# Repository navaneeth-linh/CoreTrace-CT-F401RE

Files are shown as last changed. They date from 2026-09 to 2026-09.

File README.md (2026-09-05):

# CT-F401RE Evaluation Board
**Team:** CoreTrace  
**Designer:** S Navaneeth Krishna  
**Institution:** Muthoot Institute of Technology and Science (MITS), Kerala  
**Competition:** Mixed Traces PCB Design Competition — MEC 2026  

---

## Overview
CT-F401RE is a compact STM32F401RET6 evaluation and development board 
designed for the Mixed Traces PCB Design Competition organized by 
Mixed Signals, the Electronics Association of MEC. The board is 
inspired by the STM32 NUCLEO-F401RE reference design and provides 
essential facilities for programming, debugging, and general-purpose 
embedded development.

---

## Features
- STM32F401RET6 LQFP-64 microcontroller
- USB Micro-B interface for power and communication
- SWD debug and programming header (6-pin)
- UART communication header (4-pin)
- SPI communication header (6-pin)
- I2C communication header (4-pin)
- 18 GPIO pins exposed via CN1 and CN2 headers
- 8MHz HSE crystal oscillator
- AMS1117-3.3 LDO voltage regulator (5V → 3.3V)
- 4 LED indicators (PWR / USR / TX / RX)
- Reset tactile button
- User tactile button
- BOOT0 SPDT slide switch
- 100 × 100mm 2-layer PCB
- Designed in KiCad 10.0.5

---

## Design Decisions

### Power Supply
- AMS1117-3.3 LDO chosen for simplicity, availability and low cost
- USB Micro-B as power input via VBUS (5V)
- Bulk capacitors (22µF) on both input and output of regulator
- 100nF ceramic decoupling caps on all MCU VDD pins
- Ferrite bead (120R) on VDDA/VREF+ supply for analog noise filtering
- VCAP1 = 2.2µF for STM32F401RE internal voltage regulator stability

### USB
- 22Ω series resistors on D+ and D− for signal integrity
- Internal 1.5kΩ pullup on D+ for USB Full Speed detection
- USB Micro-B connector on board edge for easy access

### Clock
- 8MHz HSE crystal with 20pF load capacitors
- Crystal placed close to PH0/PH1 pins for short traces

### BOOT0
- SPDT slide switch for easy BOOT0 selection
- FLASH position → normal boot from flash
- BOOT position → bootloader mode
- 10kΩ pulldown resistor as default LOW state

### GPIO
- CN1 exposes: 3.3V, PA0, PA1, PA8, PA9, PA10, PA15, PB1, PB2, GND
- CN2 exposes: 3.3V, PB3, PB4, PB5, PB6, PB7, PB10, PB12, PB13, GND
- All unused PC pins assigned no-connect flags

### PCB
- SMD components throughout for compact layout
- 0402 package for resistors and small capacitors
- 0805 package for LEDs and bulk capacitors
- GND copper pour on both layers
- Track widths: 0.2mm signal, 0.3mm MCU power, 0.5mm 3.3V, 0.8mm VBUS

---

## Design Status

| Task | Status |
|---|---|
| Schematic | ✅ Complete |
| ERC | ✅ Clean (0 errors, 0 warnings) |
| PCB Layout | ✅ Complete |
| Routing | ✅ Complete |
| DRC | ✅ Clean (0 errors, 1 warning) |
| Silkscreen | ✅ Complete |
| BOM | ✅ Complete |
| Documentation | ✅ Complete |

---

## Known Issues and Warnings

### DRC Warning — Footprint Mismatch
**Warning:**    

**Component:** SW1 — BOOT0 SPDT Switch

**Reason:** The SPDT switch footprint was 
modified to fix a silkscreen overlap with 
the board edge cut. The silkscreen of the 
original footprint extended beyond the PCB 
boundary causing a DRC violation. The 
footprint silkscreen was moved inward 
resulting in a minor library mismatch warning.

**Impact:** None — footprint is electrically 
correct and physically accurate. This is a 
cosmetic library mismatch only.

**DRC Summary:**
| Type | Count |
|---|---|
| Errors | 0 ✅ |
| Warnings | 1 ⚠️ |
| Unconnected nets | 0 ✅ |

---

## Screenshots

### Block Diagram 
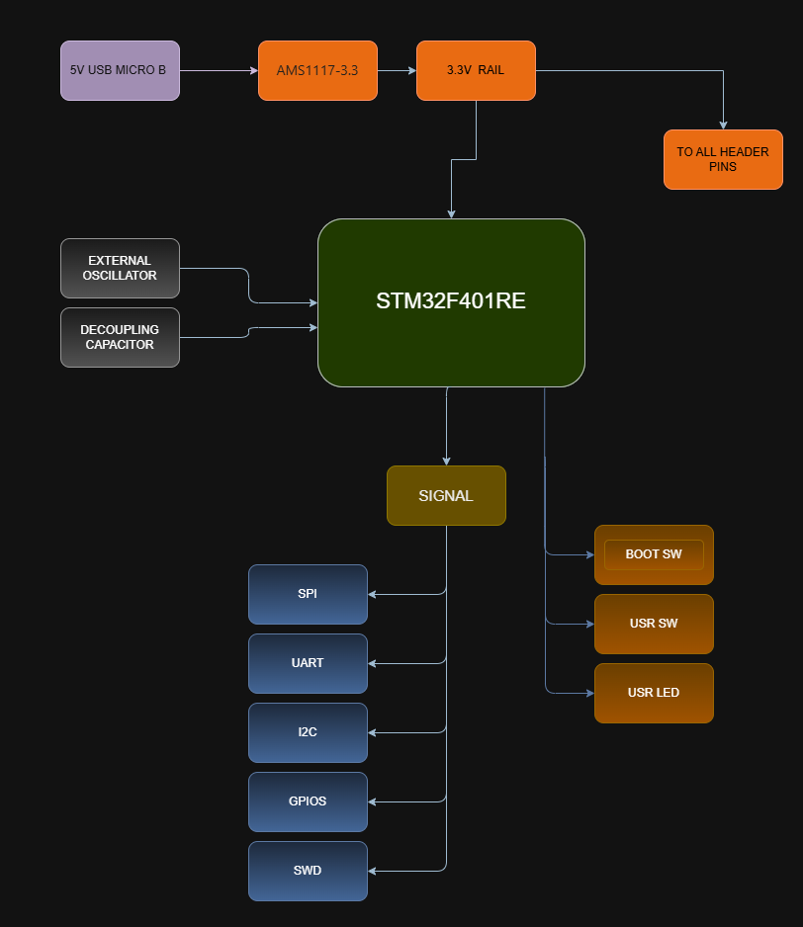
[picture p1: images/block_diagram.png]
Block Diagram


### Schematic
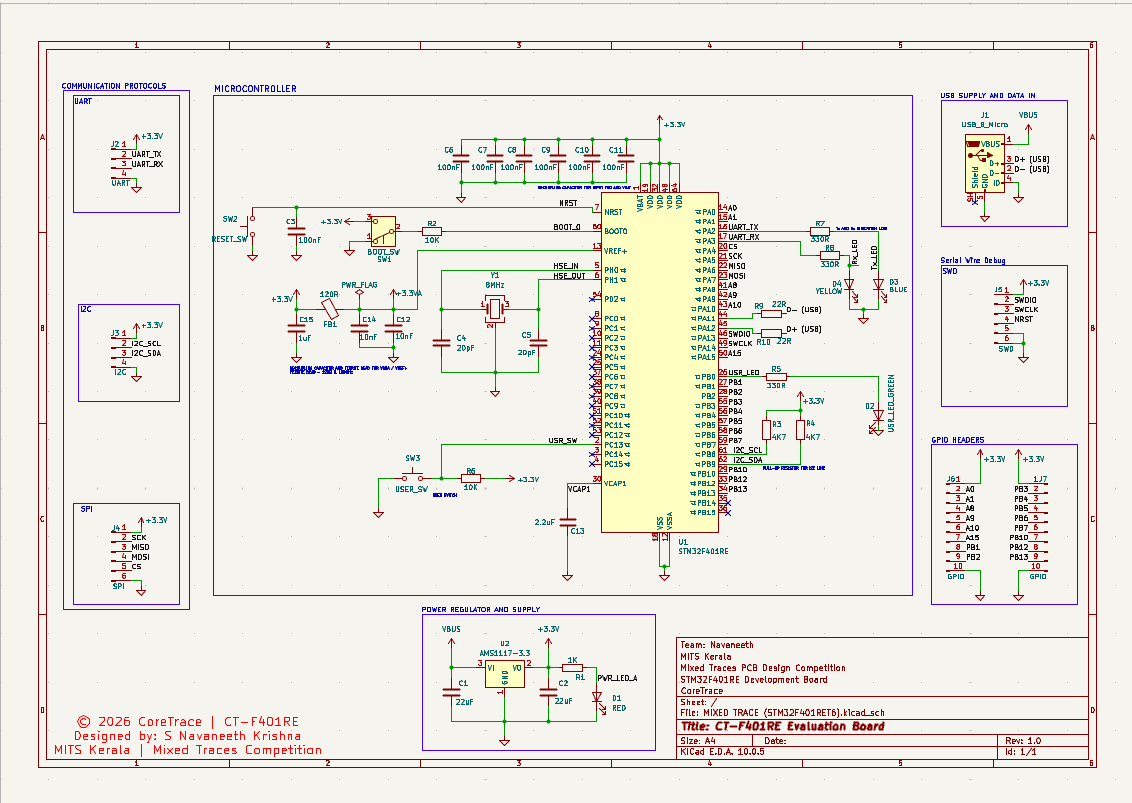
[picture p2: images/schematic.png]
Schematic


### PCB Layout
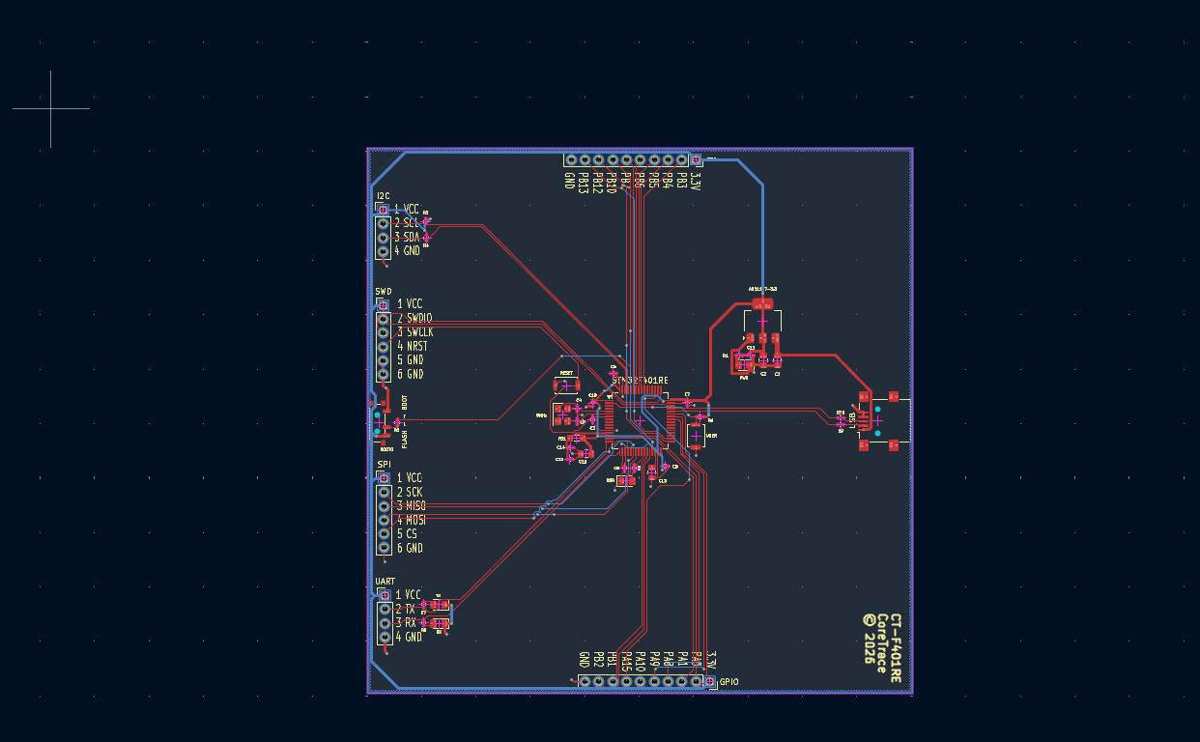
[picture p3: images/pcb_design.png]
PCB Layout


### PCB 3D View
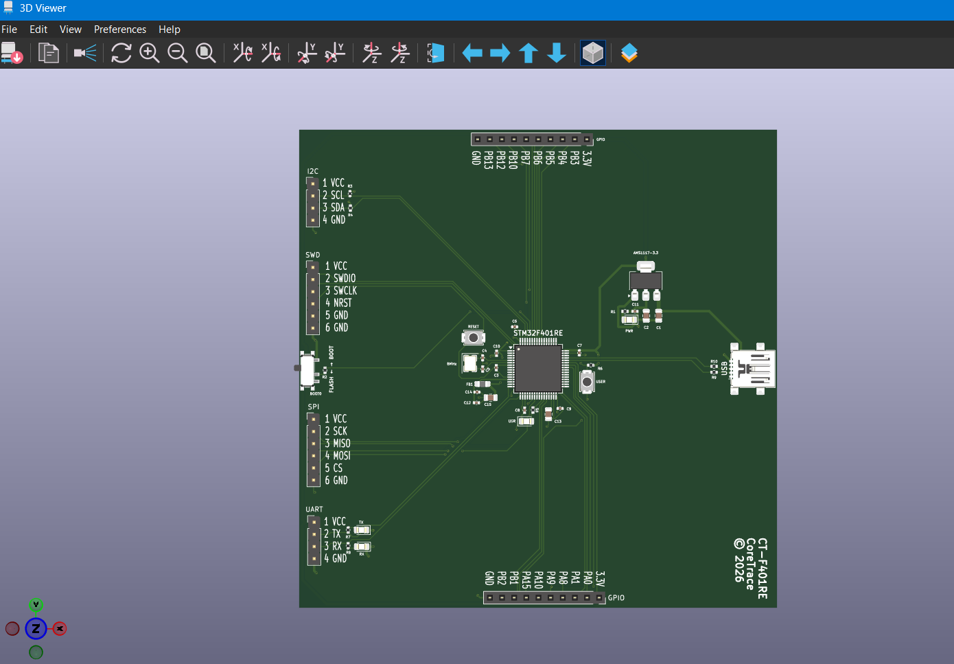
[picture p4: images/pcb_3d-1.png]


### PCB 3D View
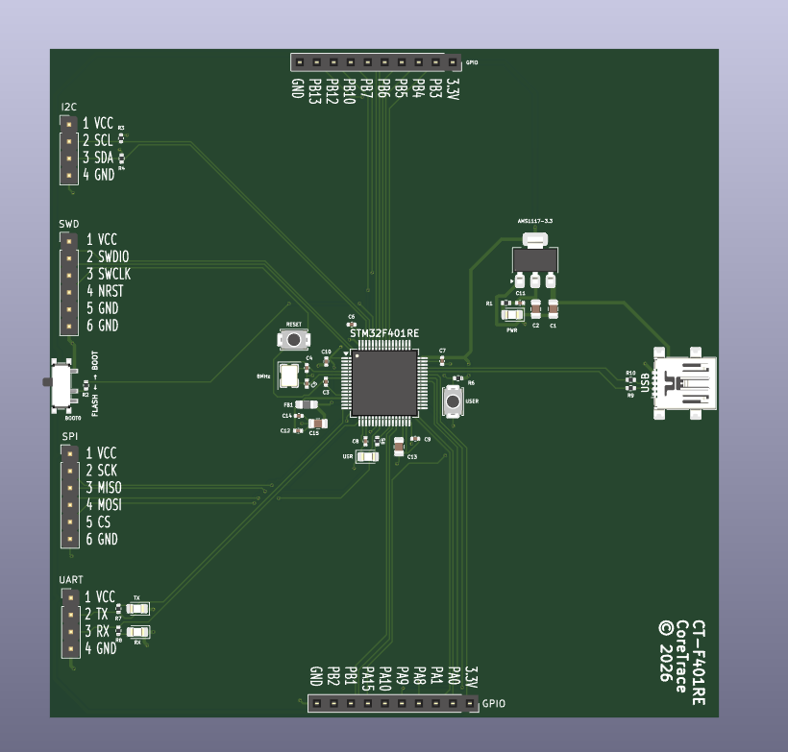
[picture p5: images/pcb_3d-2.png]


### ERC Results
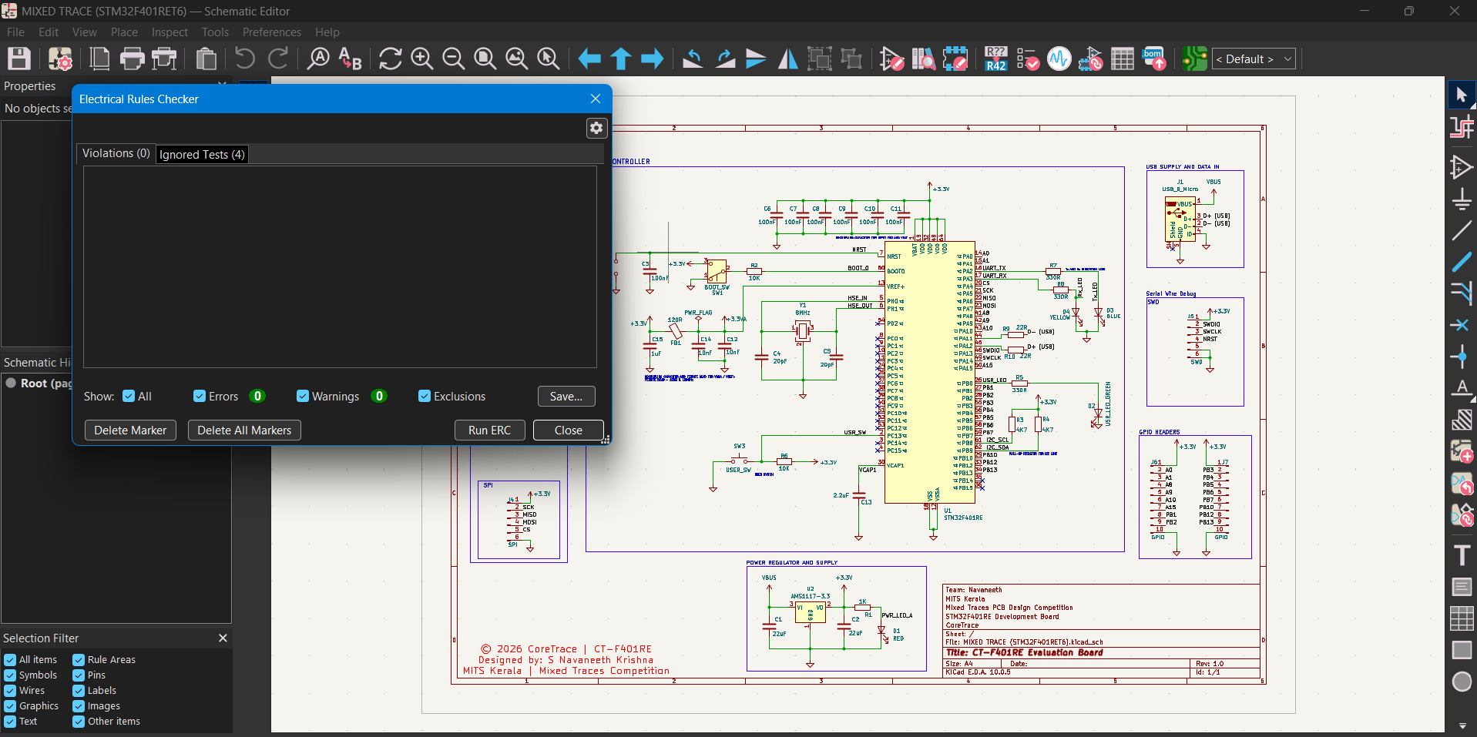
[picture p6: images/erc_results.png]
ERC


### DRC Results
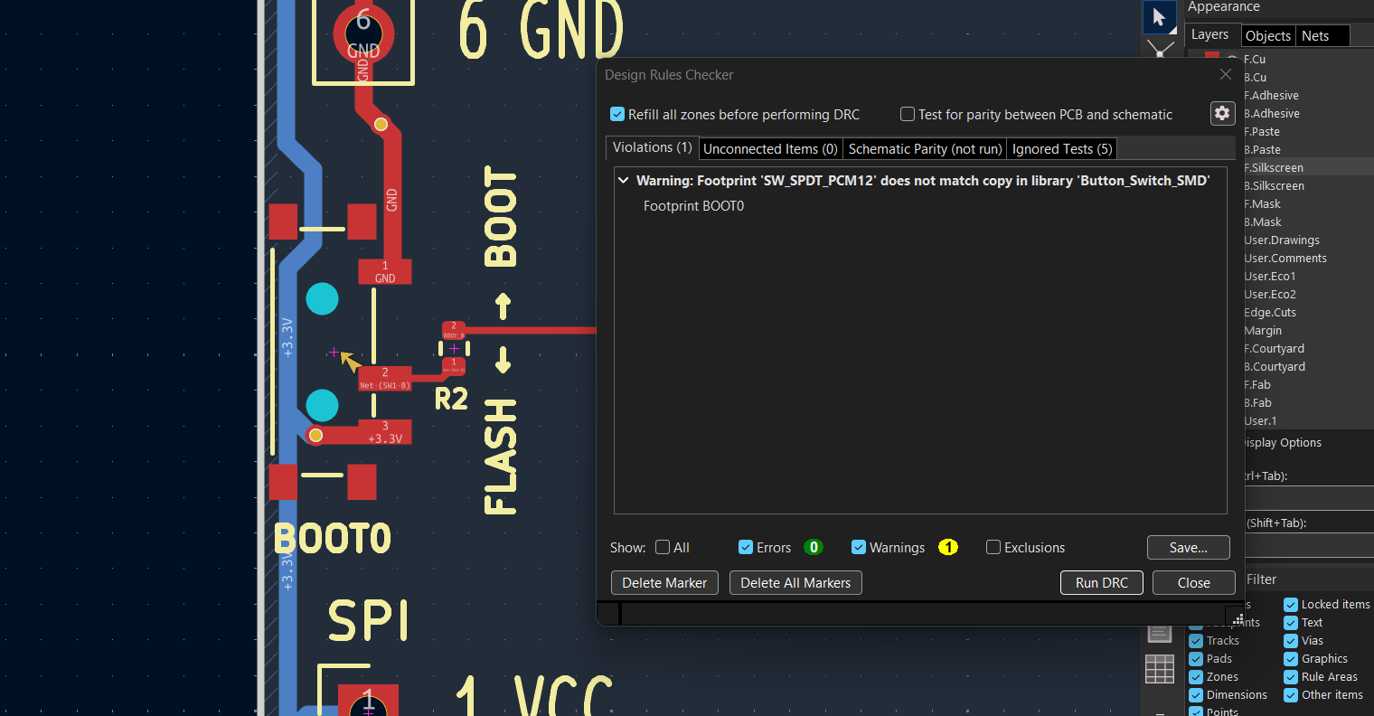
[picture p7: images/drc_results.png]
DRC


---

## Bill of Materials (BOM) with Estimated Cost

| Ref | Component | Value | Package | Qty | Unit Price (₹) | Total (₹) |
|---|---|---|---|---|---|---|
| U1 | STM32F401RET6 | MCU | LQFP-64 | 1 | ₹450 | ₹450 |
| U2 | AMS1117-3.3 | LDO Regulator | SOT-223 | 1 | ₹15 | ₹15 |
| Y1 | Crystal | 8MHz | SMD 3225 | 1 | ₹25 | ₹25 |
| C1, C2 | Capacitor | 22µF | 0805 | 2 | ₹5 | ₹10 |
| C13 | Capacitor | 2.2µF | 0805 | 1 | ₹4 | ₹4 |
| C14, C15 | Capacitor | 1µF | 0805 | 2 | ₹3 | ₹6 |
| C6,C7,C8,C9,C10,C11 | Capacitor | 100nF | 0402 | 6 | ₹2 | ₹12 |
| C3, C12 | Capacitor | 10nF | 0402 | 2 | ₹2 | ₹4 |
| C4, C5 | Capacitor | 20pF | 0402 | 2 | ₹2 | ₹4 |
| R2, R6 | Resistor | 10kΩ | 0402 | 2 | ₹1 | ₹2 |
| R3, R4 | Resistor | 4.7kΩ | 0402 | 2 | ₹1 | ₹2 |
| R1 | Resistor | 1kΩ | 0402 | 1 | ₹1 | ₹1 |
| R5, R7, R8 | Resistor | 330Ω | 0402 | 3 | ₹1 | ₹3 |
| R9, R10 | Resistor | 22Ω | 0402 | 2 | ₹1 | ₹2 |
| R_USB | Resistor | 1.5kΩ | 0402 | 1 | ₹1 | ₹1 |
| FB1 | Ferrite Bead | 120R | 0805 | 1 | ₹8 | ₹8 |
| D1 | LED | Red | 0805 | 1 | ₹5 | ₹5 |
| D2 | LED | Green | 0805 | 1 | ₹5 | ₹5 |
| D3 | LED | Blue | 0805 | 1 | ₹5 | ₹5 |
| D4 | LED | Yellow | 0805 | 1 | ₹5 | ₹5 |
| SW2 | Tactile Switch | Reset | SMD 6×6mm | 1 | ₹8 | ₹8 |
| SW3 | Tactile Switch | User | SMD 6×6mm | 1 | ₹8 | ₹8 |
| SW1 | SPDT Switch | BOOT0 | SMD | 1 | ₹12 | ₹12 |
| J1 | USB Micro-B | Connector | SMD | 1 | ₹20 | ₹20 |
| CN1, CN2 | Pin Header | 2.54mm 1×10 | THT | 2 | ₹8 | ₹16 |
| J5 | Pin Header | 2.54mm 1×06 | THT | 1 | ₹5 | ₹5 |
| J2, J3 | Pin Header | 2.54mm 1×04 | THT | 2 | ₹4 | ₹8 |
| J4 | Pin Header | 2.54mm 1×06 | THT | 1 | ₹5 | ₹5 |
| — | PCB Manufacturing | 2-layer 100×100mm | — | 1 | ₹150 | ₹150 |
| **Total** | | | | | | **₹811** |

> **Note:** Prices are approximate Indian market rates
> sourced from Robu.in, Evelta, and ElectronicsComp.
> Actual prices may vary by supplier and quantity.
> PCB cost based on single unit prototype pricing.

## Tools Used
- KiCad 10.0.5
- STM32F401RET6 Datasheet
- NUCLEO-F401RE Reference Schematic (MB1136)
- STM32F401RE Reference Manual

---

## Competition Details
**Competition:** Mixed Traces PCB Design Competition  
**Organizer:** Mixed Signals — Electronics Association of MEC  
**Reference:** STM32 NUCLEO-F401RE (MB1136)  
**Submission Date:** September 2026  

---

*© 2026 CoreTrace — S Navaneeth Krishna — MITS Kerala*

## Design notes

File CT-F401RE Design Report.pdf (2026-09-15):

# CT-F401RE EVALUATION BOARD

# Final Design Report

Team: CoreTrace

Designer: S Navaneeth Krishna

Institution: Muthoot Institute of Technology and Science (MITS), Kerala

Competition: Mixed Traces PCB Design

Tool: KiCad

1. PROBLEM STATEMENT

Design a compact and functional STM32F401RE

evaluation and development board inspired by

the STM32 NUCLEO-F401RE reference design.

The board must provide essential facilities

for programming, debugging, and general-

purpose embedded development within a

100×100mm 2-layer PCB, designed entirely

in KiCad.

2. PROPOSED SOLUTION

The CT-F401RE is a compact evaluation board

built around the STM32F401RET6 Cortex-M4

microcontroller. The design prioritizes:

- Clean power delivery via USB Micro-B

- Full debugging capability via SWD
- Complete communication interfaces
- Accessible GPIO expansion headers
- Professional silkscreen labeling
- SMD components for compact layout
3. CIRCUIT ARCHITECTURE

The board is divided into functional blocks:

POWER SECTION

- USB Micro-B provides 5V VBUS input
- AMS1117-3.3 LDO regulates 5V to 3.3V
- 22µF bulk capacitors on input and output
- 100nF ceramic decoupling caps on both sides
- Power LED indicates 3.3V rail is active

MCU SECTION

- STM32F401RET6 LQFP-64 at board center
- 100nF decoupling on all 4 VDD pins
- 100nF on VBAT pin
- 2.2µF on VCAP1 for internal regulator
- Ferrite bead (120R) on VDDA/VREF+ supply
- 1µF + 10nF + 10nF on VDDA filtering

CLOCK SECTION

- 8MHz HSE crystal oscillator

- 20pF load capacitors on PH0 and PH1
- Crystal placed close to MCU for short traces
- Internal PLL scales to 84MHz system clock

USB SECTION

- USB Micro-B connector on board edge
- 22Ω series resistors on D+ and D−
- 1.5kΩ pullup on D+ for Full Speed detect
- PA11 = USB_DM, PA12 = USB_DP

SWD SECTION

- 6-pin header (VCC/SWDIO/SWCLK/NRST/GND)
- PA13 = SWDIO, PA14 = SWCLK
- Allows external ST-Link programmer

COMMUNICATION SECTION

- UART: PA2(TX), PA3(RX) — 4-pin header
- SPI: PA4(CS), PA5(SCK), PA6(MISO),

PA7(MOSI) — 6-pin header

- I2C: PB8(SCL), PB9(SDA) — 4-pin header
- I2C pullup resistors 4.7kΩ on SCL and SDA

GPIO SECTION

- CN1: 3.3V, PA0, PA1, PA8, PA9, PA10,

PA15, PB1, PB2, GND

- CN2: 3.3V, PB3, PB4, PB5, PB6, PB7,

PB10, PB12, PB13, GND

- 18 GPIO pins total exposed

USER INTERFACE

- PWR LED (Red) — 3.3V power indicator
- USR LED (Green) — user controlled via PB0
- TX LED (Blue) — UART transmit indicator
- RX LED (Yellow) — UART receive indicator
- SW2: Reset button on NRST
- SW3: User button on PC13
- SW1: SPDT slide switch for BOOT0
4. PCB DESIGN

Board specifications:

- Size: 100 × 100mm
- Layers: 2 copper layers (F.Cu + B.Cu)
- Software: KiCad 10.0.5

Component packages:

- Resistors: 0402 SMD
- Capacitors (small): 0402 SMD
- Capacitors (bulk): 0805 SMD
- LEDs: 0805 SMD
- Ferrite bead: 0805 SMD
- Crystal: SMD 3225

Track widths:

- Signal traces: 0.2mm
- MCU power pins: 0.3mm
- 3.3V power: 0.5mm
- VBUS 5V: 0.8mm

PCB features:

- GND copper pour on both layers
- Decoupling caps placed next to MCU VDD pins
- Crystal placed close to PH0/PH1 pins
- USB connector on board edge
- GPIO headers on top and bottom edges
- All connectors and pins clearly labelled

MAJOR COMPONENTS

Component | Value | Package Cost
STM32F401RET6 MCU | LQFP-64 ₹450
AMS1117-3.3 LDO | SOT-223 ₹15
Crystal | 8MHz | SMD 3225 ₹25
USB Micro-B Connector SMD | ₹20
Capacitors | Various 0402/0805 ₹40
Resistors | Various 0402 | ₹13
LEDs | 4 colors 0805 | ₹20
Switches | 3 types SMD | ₹28
Pin Headers 2.54mm | THT | ₹29
Ferrite Bead 120R | 0805 | ₹8

PCB 2-layer 100x100mm ₹150

Total estimated cost: ₹811

6. DESIGN CONSIDERATIONS

POWER INTEGRITY

- Each VDD pin has dedicated 100nF cap
- Bulk 22µF caps for low frequency stability
- Ferrite bead isolates analog VDDA supply
- VCAP1 = 2.2µF as per STM32F401RE datasheet

SIGNAL INTEGRITY

- 22Ω USB series resistors reduce EMI
- Crystal traces kept short and equal length
- USB D+ and D− routed as matched pair
- SWD traces kept away from USB lines

USABILITY

- SPDT switch for easy BOOT0 selection
- FLASH position = normal operation
- BOOT position = bootloader mode
- 10kΩ pulldown ensures safe default state
- All header pins labelled on silkscreen
- Board name and team name on silkscreen

COST OPTIMIZATION

- SMD 0402 resistors — cheapest package
- AMS1117 over more expensive LDOs
- Standard 2.54mm headers
- No unnecessary components added
7. TESTING AND VALIDATION

ERC Results:

- Errors: 0 ✅
- Warnings: 0 ✅

DRC Results:

- Errors: 0 ✅
- Warnings: 1 ⚠️

(Footprint mismatch on SW1 — cosmetic

only, caused by silkscreen edit to fix

board edge clearance. No electrical

impact.)

- Unconnected nets: 0 ✅

Design validation:

- All minimum requirements verified
- All nets connected and routed
- All connectors labelled on silkscreen
- BOM reviewed and costed

- Schematic reviewed against datasheet
- PCB reviewed against design rules
8. CHALLENGES
- Started with wrong MCU (STM32F103C8Tx)

and had to redesign around STM32F401RET6

- VCAP1 pin unique to F401RE — not present

on F103, required careful attention

- Crystal footprint mismatch between 3-pin

symbol and 4-pin SMD package — resolved

by using Crystal_GND3_GND4 symbol

- Boot switch silkscreen overlapped board

edge — resolved by editing footprint

silkscreen inward

- First PCB attempt deleted and redesigned

for cleaner placement and routing

9. FINAL OUTCOME

The CT-F401RE evaluation board successfully

meets all competition requirements:

✅ STM32F401RET6 as main MCU

✅ USB Micro-B power and communication

✅ AMS1117-3.3 voltage regulation

✅ Complete decoupling strategy

✅ SWD debug interface

✅ UART, SPI, I2C headers

✅ 18 GPIO pins exposed

✅ 4 LED indicators

✅ Reset and user buttons

✅ BOOT0 SPDT switch

✅ 100×100mm 2-layer PCB

✅ ERC clean — 0 errors

✅ DRC clean — 0 errors

✅ Professional silkscreen

✅ Complete documentation

GitHub Repository:

https://github.com/navaneeth-linh/CoreTrace-CT-F401RE

━━━━━━━━━━━━━━━━━━━━━━━━━━━━━━━━━━━━━━━━
© 2026 CoreTrace | S Navaneeth Krishna
MITS Kerala | Mixed Traces Competition

━━━━━━━━━━━━━━━━━━━━━━━━━━━━━━━━━━━━━━━━

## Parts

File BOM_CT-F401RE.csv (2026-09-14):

Reference | Value | Footprint | Qty
C1,C2 | 22uF | Capacitor_SMD:C_0805_2012Metric | 2
C3,C6,C7,C8,C9,C10,C11 | 100nF | Capacitor_SMD:C_0402_1005Metric | 7
C4,C5 | 20pF | Capacitor_SMD:C_0402_1005Metric | 2
C12,C14 | 10nF | Capacitor_SMD:C_0402_1005Metric | 2
C13 | 2.2uF | Capacitor_SMD:C_0805_2012Metric | 1
C15 | 1uF | Capacitor_SMD:C_0805_2012Metric | 1
D1 | RED | LED_SMD:LED_0805_2012Metric_Pad1.15x1.40mm_HandSolder | 1
D2 | USR_LED_GREEN | LED_SMD:LED_0805_2012Metric_Pad1.15x1.40mm_HandSolder | 1
D3 | BLUE | LED_SMD:LED_0805_2012Metric_Pad1.15x1.40mm_HandSolder | 1
D4 | YELLOW | LED_SMD:LED_0805_2012Metric_Pad1.15x1.40mm_HandSolder | 1
FB1 | 120R | Inductor_SMD:L_0805_2012Metric_Pad1.05x1.20mm_HandSolder | 1
J1 | USB_B_Micro | Connector_USB:USB_Mini-B_Lumberg_2486_01_Horizontal | 1
J2 | UART | Connector_PinHeader_2.54mm:PinHeader_1x04_P2.54mm_Vertical | 1
J3 | I2C | Connector_PinHeader_2.54mm:PinHeader_1x04_P2.54mm_Vertical | 1
J4 | SPI | Connector_PinHeader_2.54mm:PinHeader_1x06_P2.54mm_Vertical | 1
J5 | SWD | Connector_PinHeader_2.54mm:PinHeader_1x06_P2.54mm_Vertical | 1
J6,J7 | GPIO | Connector_PinSocket_2.54mm:PinSocket_1x10_P2.54mm_Vertical | 2
R1 | 1K | Resistor_SMD:R_0402_1005Metric | 1
R2,R6 | 10K | Resistor_SMD:R_0402_1005Metric | 2
R3,R4 | 4K7 | Resistor_SMD:R_0402_1005Metric | 2
R5,R7,R8 | 330R | Resistor_SMD:R_0402_1005Metric | 3
R9,R10 | 22R | Resistor_SMD:R_0402_1005Metric | 2
SW1 | BOOT_SW | Button_Switch_SMD:SW_SPDT_PCM12 | 1
SW2 | RESET_SW | Button_Switch_SMD:SW_Push_SPST_NO_Alps_SKRK | 1
SW3 | USER_SW | Button_Switch_SMD:SW_Push_SPST_NO_Alps_SKRK | 1
U1 | STM32F401RE | Package_QFP:LQFP-64_10x10mm_P0.5mm | 1
U2 | AMS1117-3.3 | Package_TO_SOT_SMD:SOT-223-3_TabPin2 | 1
Y1 | 8MHz | Crystal:Crystal_SMD_3225-4Pin_3.2x2.5mm | 1

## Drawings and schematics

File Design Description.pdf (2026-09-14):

# CT-F401RE Evaluation Board

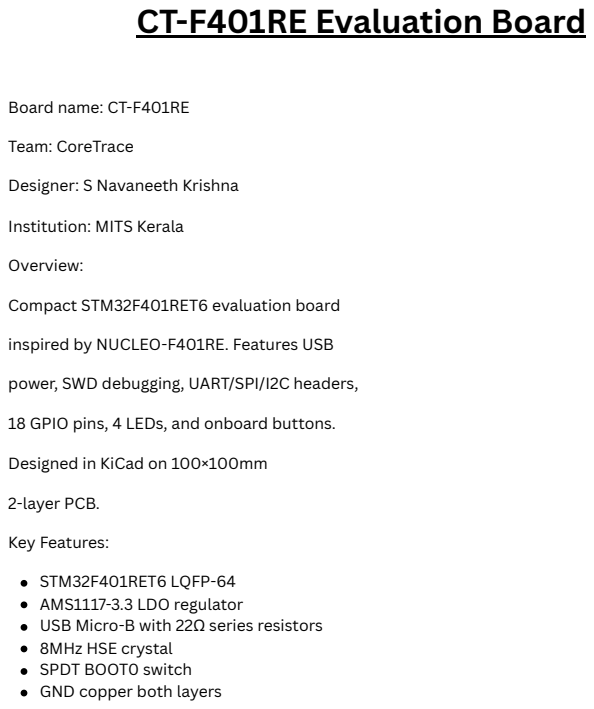
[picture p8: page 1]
Team: CoreTrace; Overview:; 2-layer PCB.; Key Features:

Board name: CT-F401RE

Designer: S Navaneeth Krishna

Institution: MITS Kerala

Compact STM32F401RET6 evaluation board

inspired by NUCLEO-F401RE. Features USB

power, SWD debugging, UART/SPI/I2C headers,

18 GPIO pins, 4 LEDs, and onboard buttons.

Designed in KiCad on 100×100mm

STM32F401RET6 LQFP-64
AMS1117-3.3 LDO regulator
USB Micro-B with 22Ω series resistors
8MHz HSE crystal
SPDT BOOT0 switch
GND copper both layers

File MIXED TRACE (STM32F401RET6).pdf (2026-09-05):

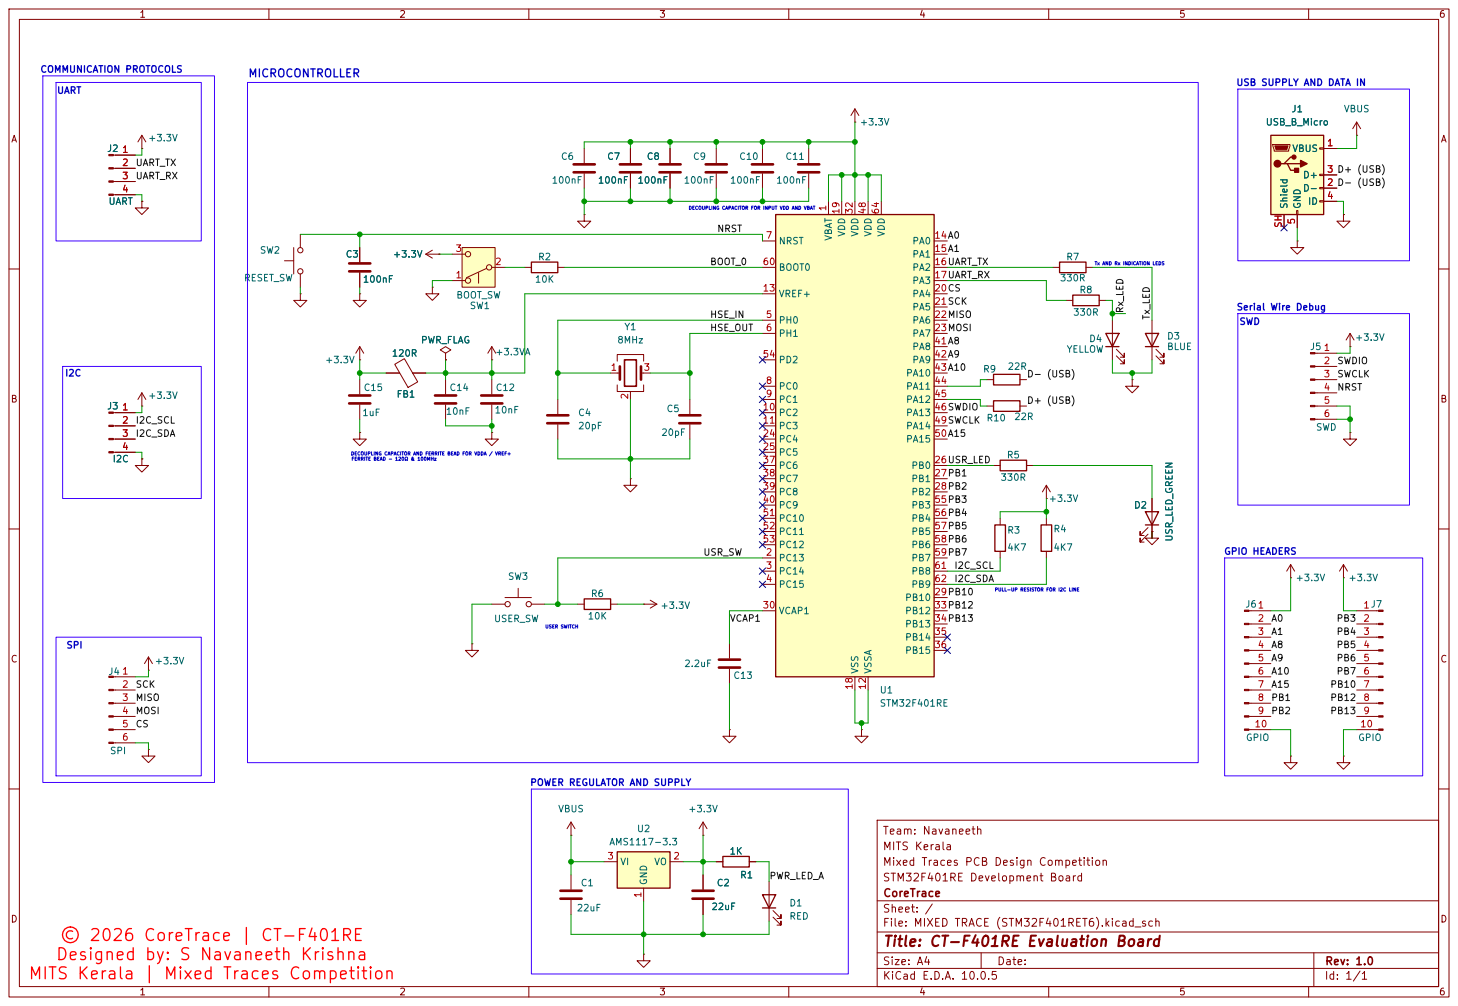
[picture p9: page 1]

Tx AND Rx INDICATION LEDS MICROCONTROLLER
100nF GND

USB SUPPLY AND DATA IN

DECOUPLING CAPACITOR FOR INPUT VDD AND VBAT I2C

DECOUPLING CAPACITOR AND FERRITE BEAD FOR VDDA / VREF+ SPI

PULL-UP RESISTOR FOR I2C LINE

POWER REGULATOR AND SUPPLY

Team: Navaneeth
MITS Kerala
Mixed Traces PCB Design Competition
STM32F401RE Development Board
CoreTrace
Sheet: /
File: MIXED TRACE (STM32F401RET6).kicad_sch
Title: CT-F401RE Evaluation Board

Designed by: S Navaneeth Krishna
MITS Kerala | Mixed Traces Competition

Size: A4 | Rev: 1.0
KiCad E.D.A. 10.0.5 | Id: 1/1

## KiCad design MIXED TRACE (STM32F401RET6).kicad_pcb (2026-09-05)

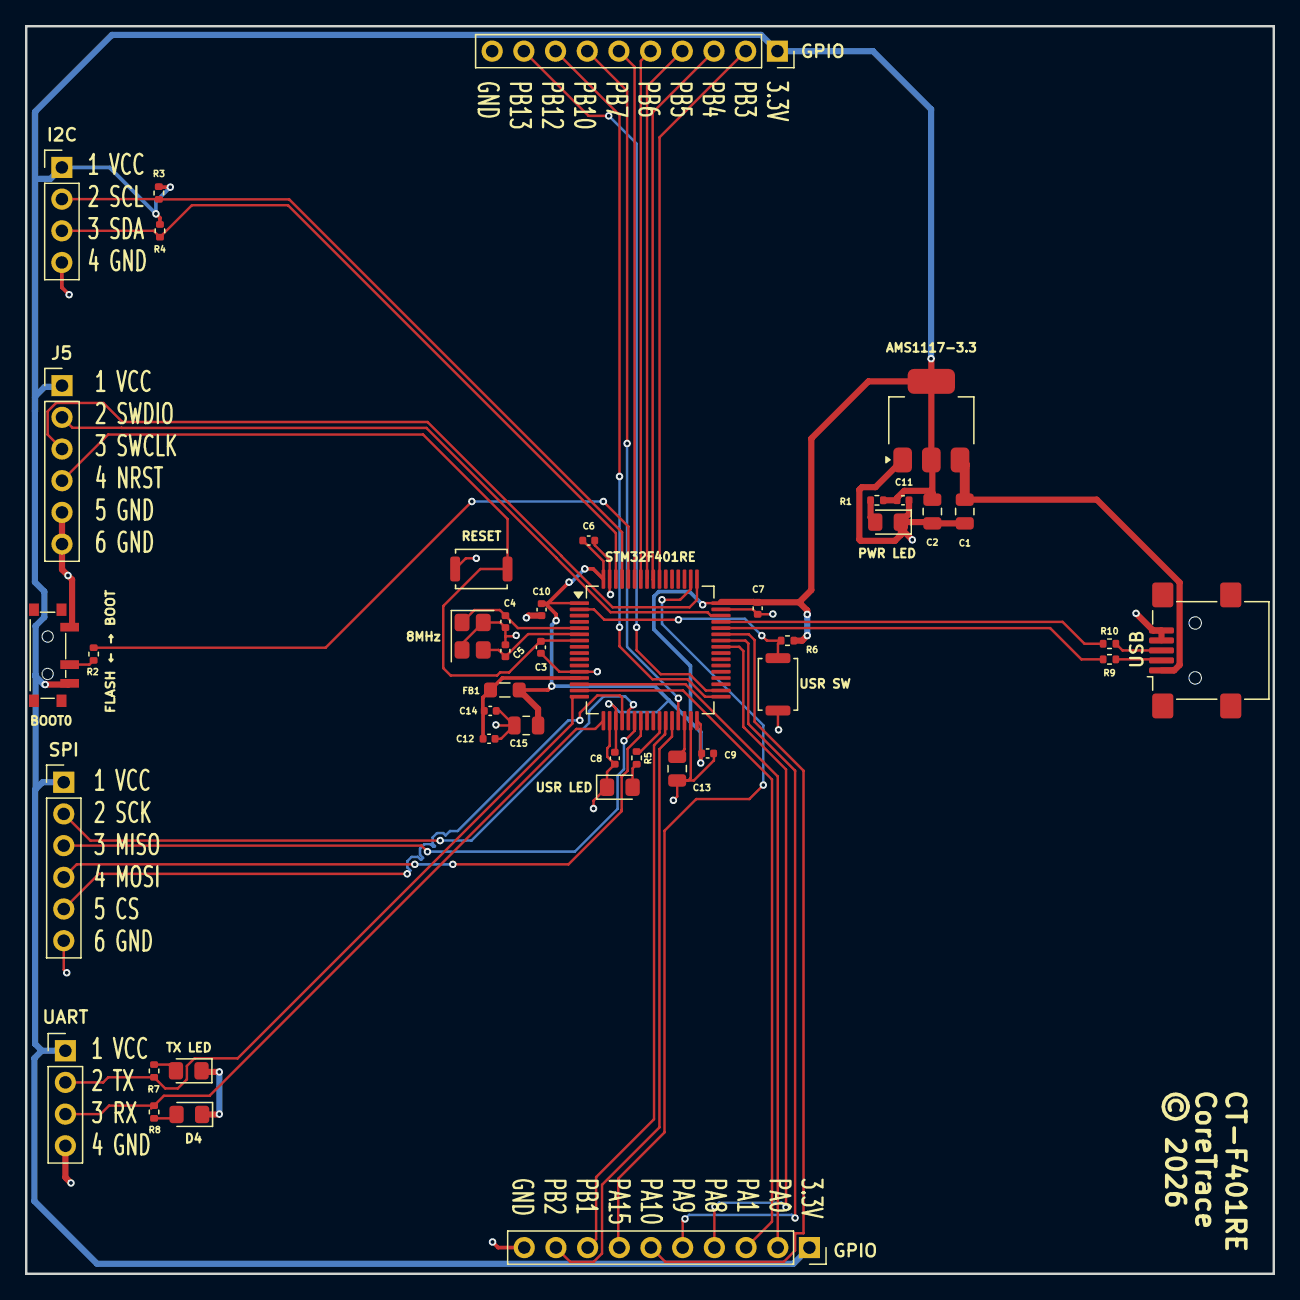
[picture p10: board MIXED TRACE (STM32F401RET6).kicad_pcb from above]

Board: 2 copper layers, 100.0 x 100.0 mm, 43 parts (0 on the bottom side), 46 nets.

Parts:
8MHz: 8MHz; Crystal_SMD_3225-4Pin_3.2x2.5mm
AMS1117-3.3: AMS1117-3.3; SOT-223-3_TabPin2
BOOT0: BOOT_SW; SW_SPDT_PCM12
C1, C2: 22uF; C_0805_2012Metric
C3, C6, C7, C8, C9, C10, C11: 100nF; C_0402_1005Metric
C4, C5: 20pF; C_0402_1005Metric
C12, C14: 10nF; C_0402_1005Metric
C13: 2.2uF; C_0805_2012Metric
C15: 1uF; C_0805_2012Metric
D4: YELLOW; LED_0805_2012Metric_Pad1.15x1.40mm_HandSolder
FB1: 120R; L_0805_2012Metric_Pad1.05x1.20mm_HandSolder
GPIO: GPIO; PinSocket_1x10_P2.54mm_Vertical
GPIO#2: GPIO; PinSocket_1x10_P2.54mm_Vertical
I2C: I2C; PinHeader_1x04_P2.54mm_Vertical
J5: SWD; PinHeader_1x06_P2.54mm_Vertical
PWR LED: RED; LED_0805_2012Metric_Pad1.15x1.40mm_HandSolder
R1: 1K; R_0402_1005Metric
R2, R6: 10K; R_0402_1005Metric
R3, R4: 4K7; R_0402_1005Metric
R5, R7, R8: 330R; R_0402_1005Metric
R9, R10: 22R; R_0402_1005Metric
RESET: RESET_SW; SW_Push_SPST_NO_Alps_SKRK
SPI: SPI; PinHeader_1x06_P2.54mm_Vertical
STM32F401RE: STM32F401RE; LQFP-64_10x10mm_P0.5mm
TX LED: BLUE; LED_0805_2012Metric_Pad1.15x1.40mm_HandSolder
UART: UART; PinHeader_1x04_P2.54mm_Vertical
USB: USB_B_Micro; USB_Mini-B_Lumberg_2486_01_Horizontal
USR LED: USR_LED_GREEN; LED_0805_2012Metric_Pad1.15x1.40mm_HandSolder
USR SW: USER_SW; SW_Push_SPST_NO_Alps_SKRK

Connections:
+3.3V: AMS1117-3.3.2 (VO), BOOT0.3 (C), C2.1, C6.1, C7.1, C8.1, C9.1, C10.1, C11.1, C15.1, FB1.2, GPIO.1, GPIO#2.1, I2C.1, J5.1, R1.1, R3.1, R4.1, R6.2, SPI.1, STM32F401RE.1 (VBAT), STM32F401RE.19 (VDD), STM32F401RE.32 (VDD), STM32F401RE.48 (VDD), STM32F401RE.64 (VDD), UART.1
+3.3VA: C12.1, C14.1, FB1.1, STM32F401RE.13 (VREF+)
/A0: GPIO#2.2, STM32F401RE.14 (PA0)
/A1: GPIO#2.3, STM32F401RE.15 (PA1)
/A8: GPIO#2.4, STM32F401RE.41 (PA8)
/A9: GPIO#2.5, STM32F401RE.42 (PA9)
/A10: GPIO#2.6, STM32F401RE.43 (PA10)
/A15: GPIO#2.7, STM32F401RE.50 (PA15)
/BOOT_0: R2.2, STM32F401RE.60 (BOOT0)
/CS: SPI.5, STM32F401RE.20 (PA4)
/D+ (USB): R10.1, USB.3 (D+)
/D- (USB): R9.1, USB.2 (D-)
/HSE_IN: 8MHz.1, C4.1, STM32F401RE.5 (PH0)
/HSE_OUT: 8MHz.3, C5.1, STM32F401RE.6 (PH1)
/I2C_SCL: I2C.2, R3.2, STM32F401RE.61 (PB8)
/I2C_SDA: I2C.3, R4.2, STM32F401RE.62 (PB9)
/MISO: SPI.3, STM32F401RE.22 (PA6)
/MOSI: SPI.4, STM32F401RE.23 (PA7)
/NRST: C3.1, J5.4, RESET.2, STM32F401RE.7 (NRST)
/PB1: GPIO#2.8, STM32F401RE.27 (PB1)
/PB2: GPIO#2.9, STM32F401RE.28 (PB2)
/PB3: GPIO.2, STM32F401RE.55 (PB3)
/PB4: GPIO.3, STM32F401RE.56 (PB4)
/PB5: GPIO.4, STM32F401RE.57 (PB5)
/PB6: GPIO.5, STM32F401RE.58 (PB6)
/PB7: GPIO.6, STM32F401RE.59 (PB7)
/PB10: GPIO.7, STM32F401RE.29 (PB10)
/PB12: GPIO.8, STM32F401RE.33 (PB12)
/PB13: GPIO.9, STM32F401RE.34 (PB13)
/PWR_LED_A: PWR LED.2 (A), R1.2
/Rx_LED: D4.2 (A), R8.1
/SCK: SPI.2, STM32F401RE.21 (PA5)
/SWCLK: J5.3, STM32F401RE.49 (PA14)
/SWDIO: J5.2, STM32F401RE.46 (PA13)
/Tx_LED: R7.1, TX LED.2 (A)
/UART_RX: R8.2, STM32F401RE.17 (PA3), UART.3
/UART_TX: R7.2, STM32F401RE.16 (PA2), UART.2
/USR_LED: R5.2, STM32F401RE.26 (PB0)
/USR_SW: R6.1, STM32F401RE.2 (PC13), USR SW.2
/VCAP1: C13.2, STM32F401RE.30 (VCAP1)
GND: 8MHz.2 (G), 8MHz.4 (G), AMS1117-3.3.1 (GND), BOOT0.1 (A), C1.2, C2.2, C3.2, C4.2, C5.2, C6.2, C7.2, C8.2, C9.2, C10.2, C11.2, C12.2, C13.1, C14.2, C15.2, D4.1 (K), GPIO.10, GPIO#2.10, I2C.4, J5.5, J5.6, PWR LED.1 (K), RESET.1, SPI.6, STM32F401RE.12 (VSSA), STM32F401RE.18 (VSS), STM32F401RE.31 (VSS), STM32F401RE.47 (VSS), STM32F401RE.63 (VSS), TX LED.1 (K), UART.4, USB.4 (ID), USB.5 (GND), USR LED.1 (K), USR SW.1
unnamed: R5.1, USR LED.2 (A)
unnamed: BOOT0.2 (B), R2.1
unnamed: R9.2, STM32F401RE.44 (PA11)
unnamed: R10.2, STM32F401RE.45 (PA12)
VBUS: AMS1117-3.3.3 (VI), C1.1, USB.1 (VBUS)

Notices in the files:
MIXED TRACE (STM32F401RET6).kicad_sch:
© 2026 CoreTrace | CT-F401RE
